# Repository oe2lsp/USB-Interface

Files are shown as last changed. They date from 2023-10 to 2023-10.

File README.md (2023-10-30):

# USB Interface

primitive and simple USB interfave for classic Ham Radio transceivers. 
- Brings the TRX to the 21st century and makes the operation of digi modes reliable and easy. 
- No more cables and adapters 
- KiCad based

Fits into Yaesu FT987 and FT817 (no Filters installed).

Components used:
- USB-Hub TUSB2036
- UART Interface: FT231XS
- Soundcard PCM2906[C] 

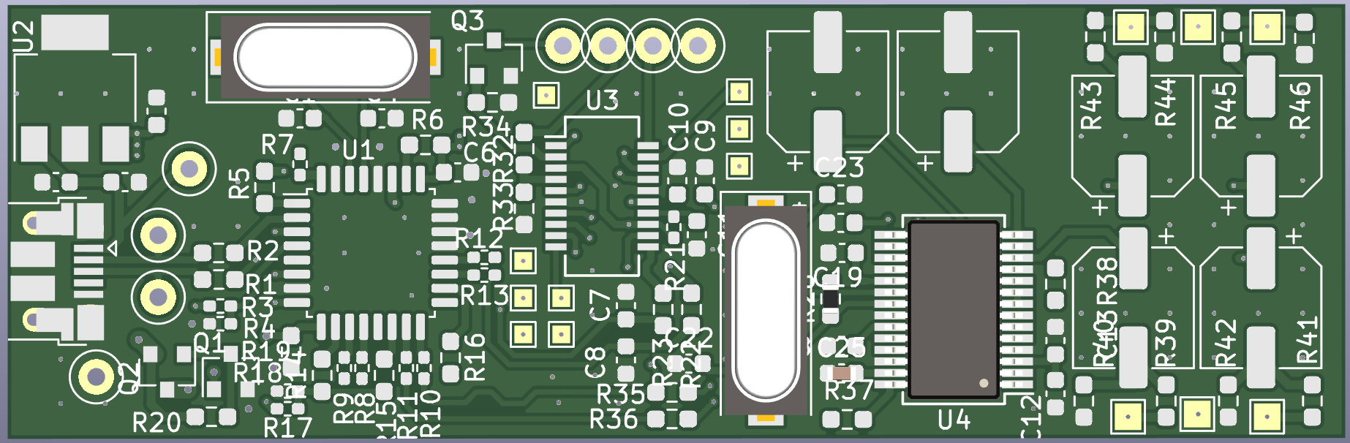
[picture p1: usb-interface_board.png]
PCB

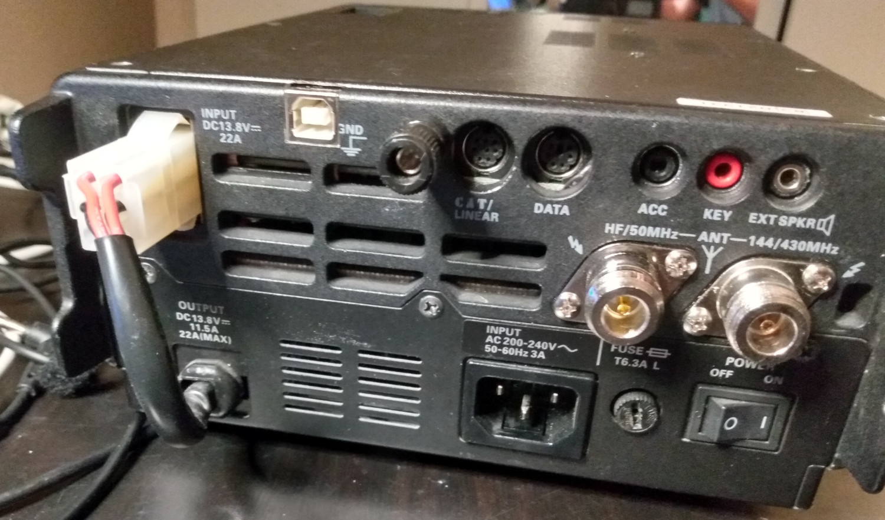
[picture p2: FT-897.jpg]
FT897

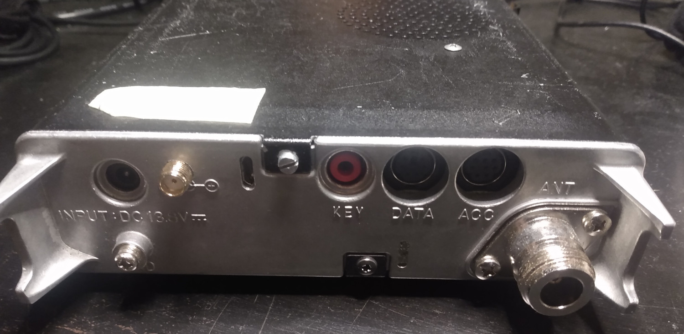
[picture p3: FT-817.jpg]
FT817


Down Side:
- only uses half of dynamic range at RX audio-chain as Yaesu TRX provide half of amplitude the IC can handle.

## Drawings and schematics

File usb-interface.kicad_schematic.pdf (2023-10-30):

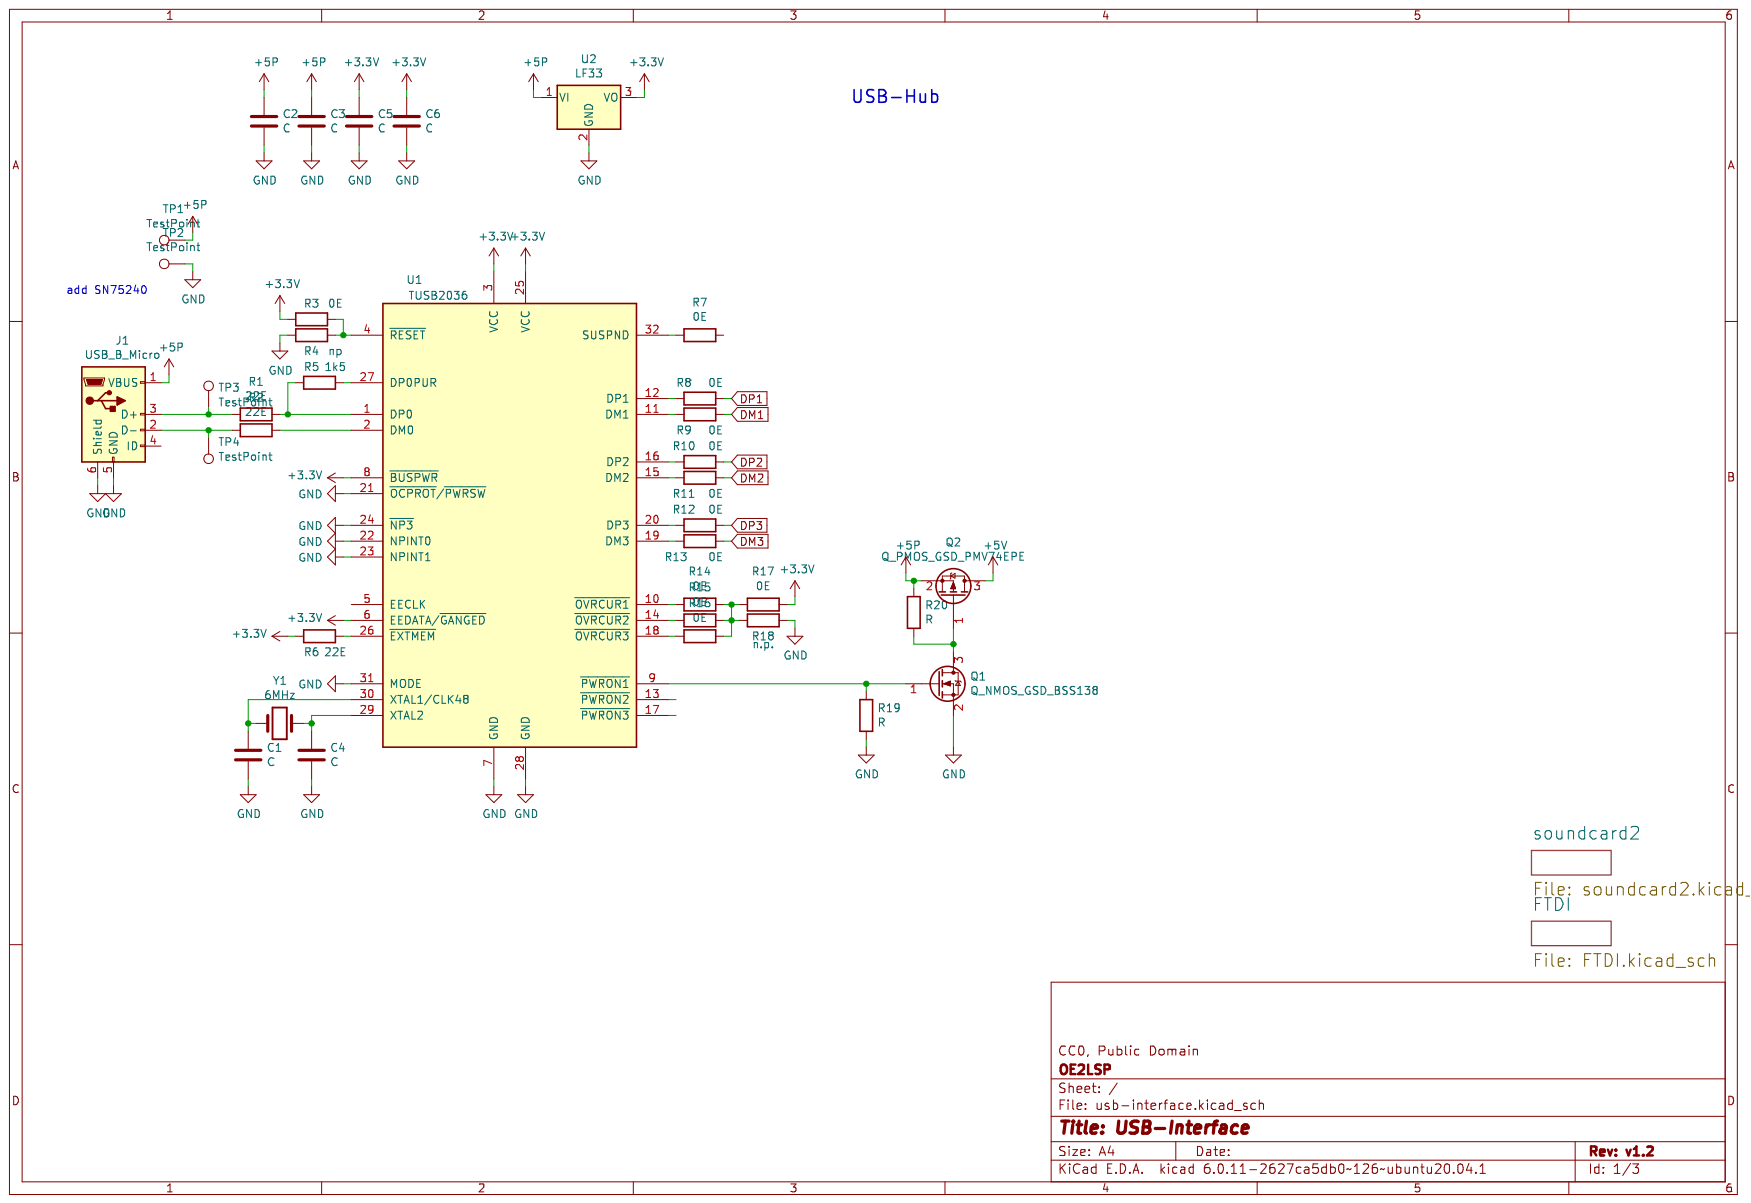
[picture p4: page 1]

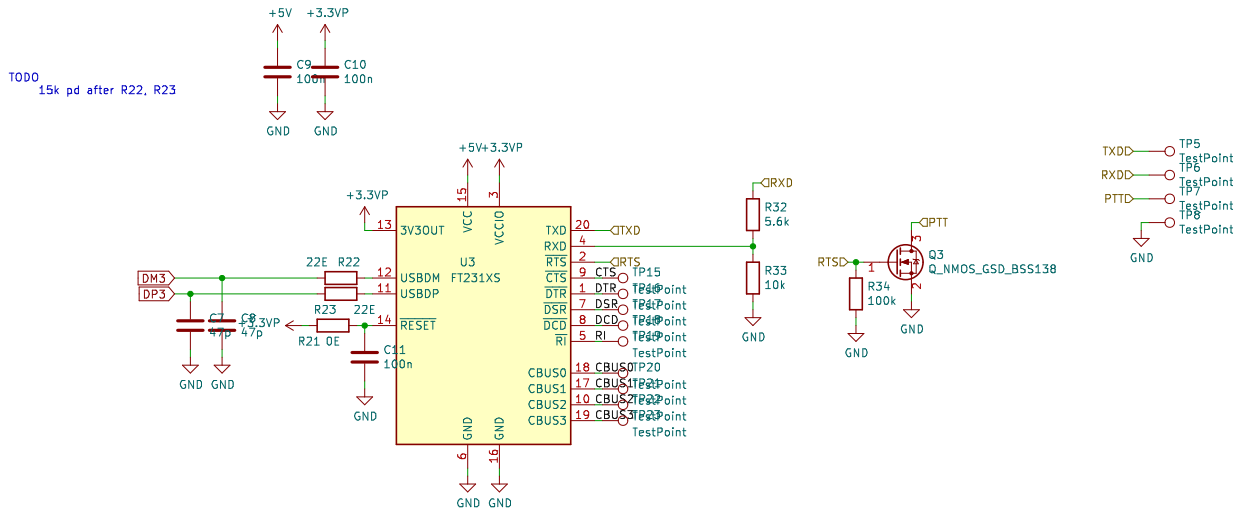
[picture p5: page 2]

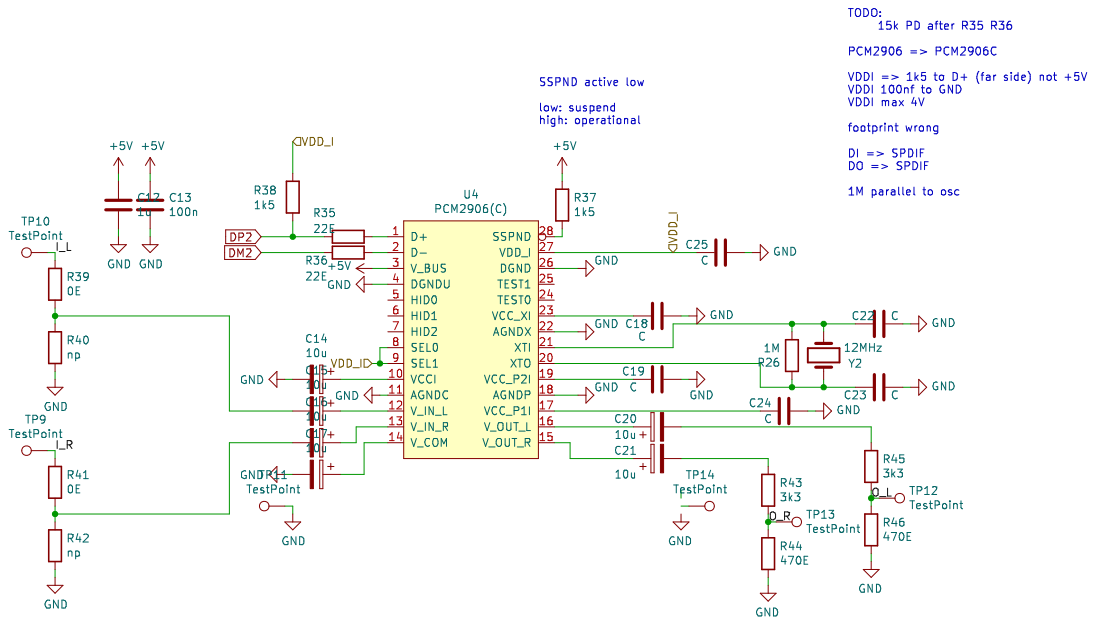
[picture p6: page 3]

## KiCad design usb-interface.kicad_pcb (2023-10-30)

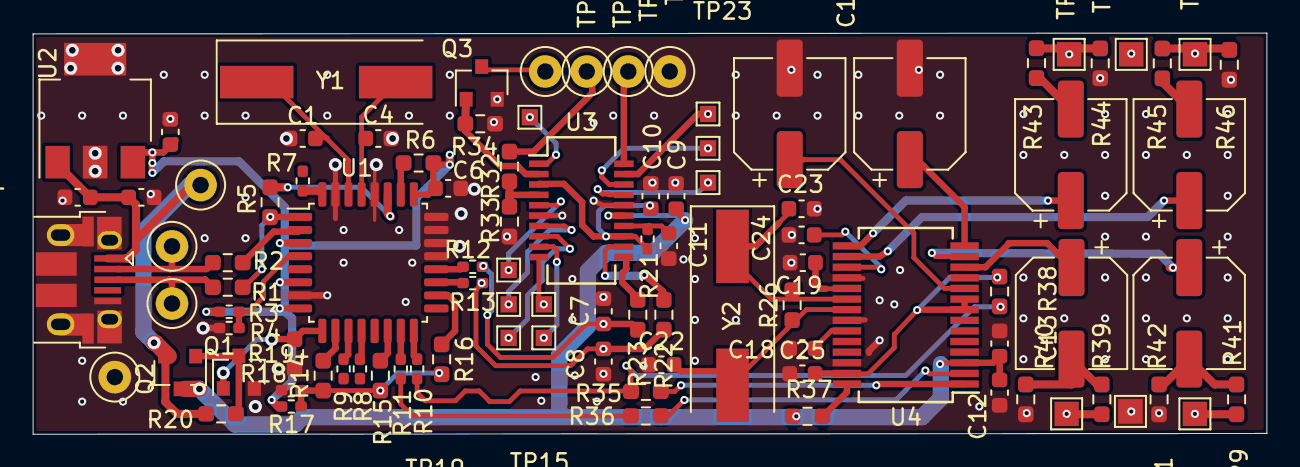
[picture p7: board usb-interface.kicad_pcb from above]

Board: 2 copper layers, 75.5 x 24.5 mm, 97 parts (0 on the bottom side), 71 nets.

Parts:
C1, C2, C3, C4, C5, C6, C18, C19, C22, C23, C24, C25: C; C_0603_1608Metric
C7, C8: 47p; C_0603_1608Metric
C9, C10, C11, C13: 100n; C_0603_1608Metric
C12: 1u; C_0603_1608Metric
C14, C15, C16, C17, C20, C21: 10u; CP_Elec_6.3x5.9
J1: USB_B_Micro; USB_Micro-B_Amphenol_10103594-0001LF_Horizontal
Q1, Q3: Q_NMOS_GSD_BSS138; SOT-23
Q2: Q_PMOS_GSD_PMV74EPE; SOT-23
R1, R2, R6, R22, R23, R35, R36: 22E; R_0603_1608Metric_Pad0.98x0.95mm_HandSolder
R3, R7, R8, R9, R10, R11, R12, R13, R17, R21: 0E; R_0402_1005Metric_Pad0.72x0.64mm_HandSolder
R4: np; R_0402_1005Metric_Pad0.72x0.64mm_HandSolder
R5, R37, R38: 1k5; R_0603_1608Metric_Pad0.98x0.95mm_HandSolder
R14, R15, R16, R39, R41: 0E; R_0603_1608Metric_Pad0.98x0.95mm_HandSolder
R18: n.p.; R_0402_1005Metric_Pad0.72x0.64mm_HandSolder
R19, R20: R; R_0603_1608Metric_Pad0.98x0.95mm_HandSolder
R26: 1M; R_0603_1608Metric_Pad0.98x0.95mm_HandSolder
R32: 5.6k; R_0603_1608Metric_Pad0.98x0.95mm_HandSolder
R33: 10k; R_0603_1608Metric_Pad0.98x0.95mm_HandSolder
R34: 100k; R_0603_1608Metric_Pad0.98x0.95mm_HandSolder
R40, R42: np; R_0603_1608Metric_Pad0.98x0.95mm_HandSolder
R43, R45: 3k3; R_0603_1608Metric_Pad0.98x0.95mm_HandSolder
R44, R46: 470E; R_0603_1608Metric_Pad0.98x0.95mm_HandSolder
TP1, TP2, TP3, TP4, TP5, TP6, TP7, TP8: TestPoint; TestPoint_Loop_D1.80mm_Drill1.0mm_Beaded
TP9, TP10, TP11, TP12, TP13, TP14: TestPoint; TestPoint_Pad_1.5x1.5mm
TP15, TP16, TP17, TP18, TP19, TP20, TP21, TP22, TP23: TestPoint; TestPoint_Pad_1.0x1.0mm
U1: TUSB2036; LQFP-32_7x7mm_P0.8mm
U2: LF33; SOT-223-3_TabPin2
U3: FT231XS; SSOP-20_3.9x8.7mm_P0.635mm
U4: PCM2906(C); SSOP-28_5.3x10.2mm_P0.65mm
Y1: 6MHz; Crystal_SMD_HC49-SD
Y2: 12MHz; Crystal_SMD_HC49-SD

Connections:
+3.3VP: C10.1, R21.2, U3.3 (VCCIO), U3.13 (3V3OUT)
+3V3: C5.1, C6.1, R3.2, R6.1, R17.1, U1.3 (VCC), U1.6 (EEDATA/~GANGED), U1.8 (~BUSPWR), U1.25 (VCC), U2.3 (VO)
+5P: C2.1, C3.1, J1.1 (VBUS), Q2.2 (S), R20.2, TP1.1, U2.1 (VI)
+5V: C9.1, C12.1, C13.1, Q2.3 (D), R37.2, U3.15 (VCC), U4.3 (V_BUS)
/FTDI/CBUS0: TP20.1, U3.18 (CBUS0)
/FTDI/CBUS1: TP21.1, U3.17 (CBUS1)
/FTDI/CBUS2: TP22.1, U3.10 (CBUS2)
/FTDI/CBUS3: TP23.1, U3.19 (CBUS3)
/FTDI/CTS: TP15.1, U3.9 (~CTS)
/FTDI/DCD: TP18.1, U3.8 (~DCD)
/FTDI/DSR: TP17.1, U3.7 (~DSR)
/FTDI/DTR: TP16.1, U3.1 (~DTR)
/FTDI/PTT: Q3.3 (D), TP7.1
/FTDI/RI: TP19.1, U3.5 (~RI)
/FTDI/RTS: Q3.1 (G), R34.1, U3.2 (~RTS)
/FTDI/RXD: R32.1, TP6.1
/FTDI/TXD: TP5.1, U3.20 (TXD)
/soundcard2/I_L: R39.2, TP10.1
/soundcard2/I_R: R41.2, TP9.1
/soundcard2/O_L: R45.1, R46.2, TP12.1
/soundcard2/O_R: R43.1, R44.2, TP13.1
/soundcard2/VDD_I: C25.2, R38.2, U4.8 (SEL0), U4.9 (SEL1), U4.27 (VDD_I)
DM2: R11.1, R36.2
DM3: C8.1, R13.1, R22.2
DP2: R10.1, R35.2, R38.1
DP3: C7.1, R12.2, R23.2
GND: C1.2, C2.2, C3.2, C4.2, C5.2, C6.2, C7.2, C8.2, C9.2, C10.2, C11.2, C12.2, C13.2, C14.2, C17.2, C18.1, C19.1, C22.1, C23.1, C24.1, C25.1, J1.5 (GND), J1.6 (Shield), Q1.2 (S), Q3.2 (S), R4.2, R18.1, R19.1, R33.2, R34.2, R40.1, R42.1, R44.1, R46.1, TP2.1, TP8.1, TP11.1, U1.7 (GND), U1.21 (~OCPROT/~PWRSW), U1.22 (NPINT0), U1.23 (NPINT1), U1.24 (~NP3), U1.28 (GND), U1.31 (MODE), U2.2 (GND), U3.6 (GND), U3.16 (GND), U4.4 (DGNDU), U4.11 (AGNDC), U4.18 (AGNDP), U4.22 (AGNDX), U4.26 (DGND)
unnamed: C1.1, U1.30 (XTAL1/CLK48), Y1.1
unnamed: C4.1, U1.29 (XTAL2), Y1.2
unnamed: C11.1, R21.1, U3.14 (~RESET)
unnamed: C14.1, U4.10 (VCCI)
unnamed: C15.1, U4.12 (V_IN_L)
unnamed: C15.2, R39.1, R40.2
unnamed: C16.1, U4.13 (V_IN_R)
unnamed: C16.2, R41.1, R42.2
unnamed: C17.1, U4.14 (V_COM)
unnamed: C18.2, U4.23 (VCC_XI)
unnamed: C19.2, U4.19 (VCC_P2I)
unnamed: C20.1, U4.16 (V_OUT_L)
unnamed: C20.2, R45.2
unnamed: C21.1, U4.15 (V_OUT_R)
unnamed: C21.2, R43.2
unnamed: C22.2, R26.1, U4.21 (XTI), Y2.2
unnamed: C23.2, R26.2, U4.20 (XTO), Y2.1
unnamed: C24.2, U4.17 (VCC_P1I)
unnamed: J1.2 (D-), R2.2, TP4.1
unnamed: J1.3 (D+), R1.2, TP3.1
unnamed: Q1.1 (G), R19.2, U1.9 (~PWRON1)
unnamed: Q1.3 (D), Q2.1 (G), R20.1
unnamed: R1.1, R5.2, U1.1 (DP0)
unnamed: R2.1, U1.2 (DM0)
unnamed: R3.1, R4.1, U1.4 (~RESET)
unnamed: R5.1, U1.27 (DP0PUR)
unnamed: R6.2, U1.26 (~EXTMEM)
unnamed: R7.2, U1.32 (SUSPND)
unnamed: R8.2, U1.12 (DP1)
unnamed: R9.2, U1.11 (DM1)
unnamed: R10.2, U1.16 (DP2)
unnamed: R11.2, U1.15 (DM2)
unnamed: R12.1, U1.20 (DP3)
unnamed: R13.2, U1.19 (DM3)
unnamed: R14.1, R15.1, R16.1, R17.2, R18.2
unnamed: R14.2, U1.10 (~OVRCUR1)
unnamed: R15.2, U1.14 (~OVRCUR2)
unnamed: R16.2, U1.18 (~OVRCUR3)
unnamed: R22.1, U3.12 (USBDM)
unnamed: R23.1, U3.11 (USBDP)
unnamed: R32.2, R33.1, U3.4 (RXD)
unnamed: R35.1, U4.1 (D+)
unnamed: R36.1, U4.2 (D-)
unnamed: R37.1, U4.28 (SSPND)

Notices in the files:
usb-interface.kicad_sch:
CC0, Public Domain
